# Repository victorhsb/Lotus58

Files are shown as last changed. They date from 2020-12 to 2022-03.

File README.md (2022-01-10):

# Lotus 58

Starting with simple tweaks to the Lily58 Glow before ordering a set of PCB's it quickly spiraled out of control, and I ended up with what wasn't quite a Lily58 anymore, and although very similar in layout, it is no longer compatible with plate and case design. 

Because of this, it was renamed Lotus58, referencing another flower much like the lily in the name Lily58.

# Lotus 58 Glow

Lotus 58 Glow
(photo from reddit by u/bduzik)

- Layout very similar to the original Lily58 family
- Per key RGB and RGB underglow
- Kaihl Hot-swap sockets for MX compatible switches
- Can be used as a standalone Gamepad for either hand
- Optional 0.91" OLED Screens and rotary encoders (one each per side)
- All components through-hole and easily soldered for beginners (SMD option for diodes)
- Designed with a sandwich-style plate/case as part of the design

# Layout variations

- Optional plate layout with OLED screen (Encoder can be placed on upper thumb key position)
- Optional plate layout with rotary encoder (Removes OLED screen for that side)  
- Optional plate layout with no hole for OLED or upper encoder (Encoder can be placed on upper thumb key position)

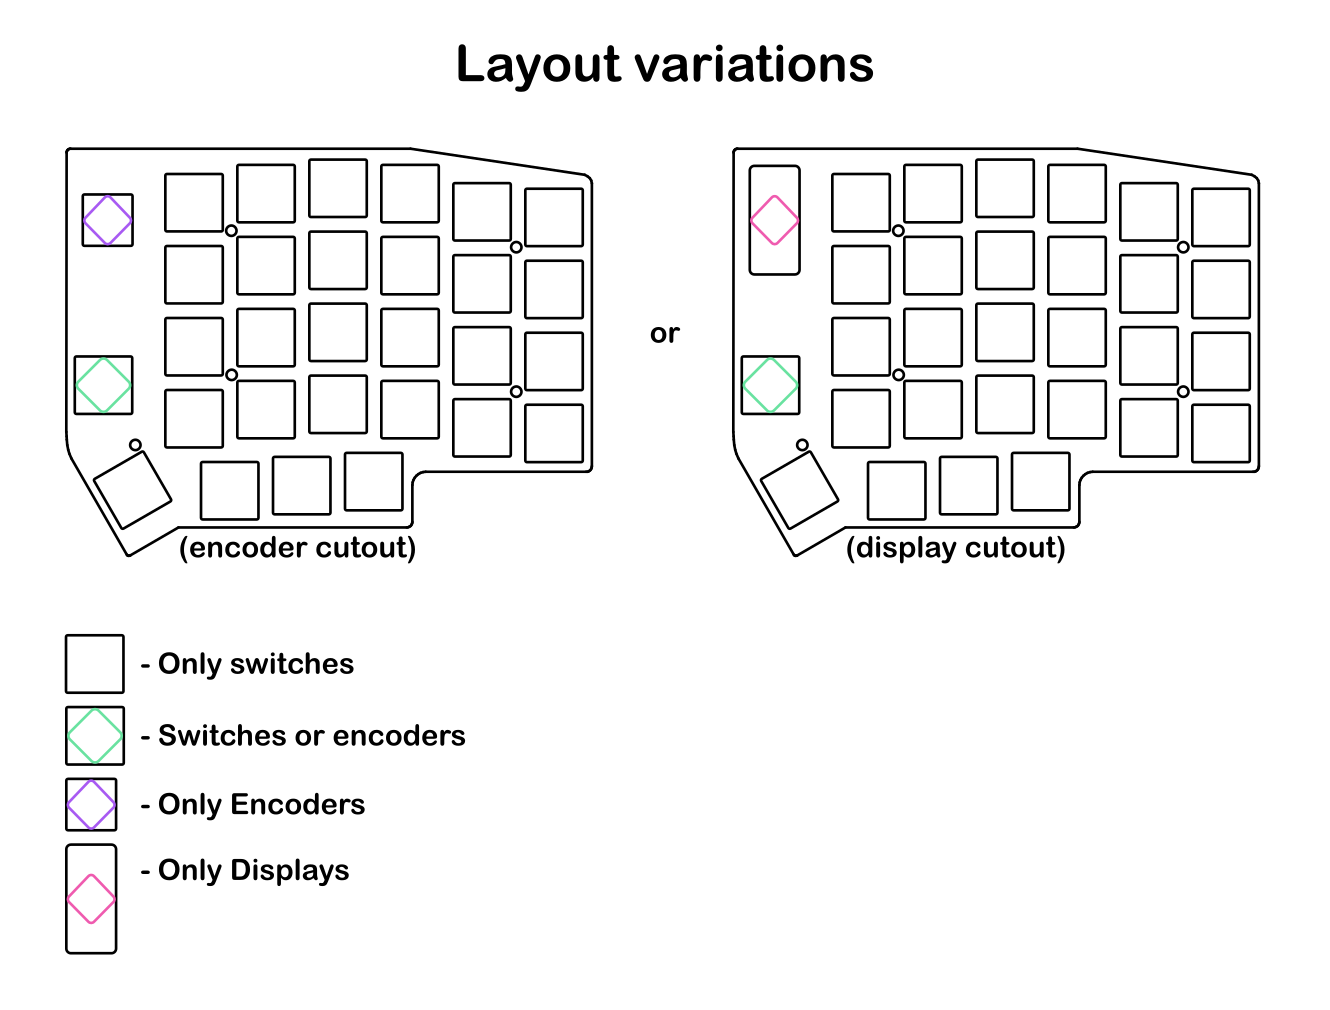
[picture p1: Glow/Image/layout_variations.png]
Layout variations Layout Variations


# Parts needed

| Name of part | Qty. | Optional | Remarks | Aliexpress |
| --- | ---- | --- | --- | --- |
| PCB | 2 | X | 1,6mm thick | X |
| Top plate | 2 | X | Optional layouts for OLED or encoder in top position. | X |
| Bottom plate | 2 | X | X | X |
| Kailh hotswap socket | 56-58 | X | Qty. depends on layout. | [link](https://www.aliexpress.com/item/-/4001051840976.html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) |
| Diodes 1N4841 (TH) or 1N4148W (SMD) | 56-58 | X | Qty. depends on layout. TH recommended for beginners. | [link(TH)](https://www.aliexpress.com/item/HOT-SELL-100-PCS-1N4148-DO-35-IN4148-Silicon-Switching-Diode-FREE-SHIPPMENT/32660088529.html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) or [link(SMD)](https://www.aliexpress.ru/item/-/1005002059571417.html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) |
| Capacitors 100 nF | 0-4 | ✔ | Qty. depends on layout. 2 needed for each encoder installed. | [link](https://www.aliexpress.com/item/-/32971478818.html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) |
| Resistor 4.7 kOhm | 2 | X | Meant to be mounted only on one side | [link](https://www.aliexpress.com/item/-/32847047012.html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) |
| 0.91" OLED Display | 0-2 | ✔ | Qty. depends on layout. | [link](https://www.aliexpress.com/item/-/4001028384269.html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) |
| TRRS jack PJ-320A | 2 | X | X | [link](https://www.aliexpress.com/item/-/4000114275750.html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) |
| M2 * 10 mm standoff | 10 | X | Rounded, max 3.7 mm in diameter | [link](https://www.aliexpress.com/item/-/32863484622.html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) |
| M2 * 4 mm screw | 20 | X | 4-8 mm length fits, low profile hex head recommended | [link](https://www.aliexpress.com/item/-/32966917947.html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) |
| TRRS cable | 1 | X | Needs to be 4 poles, more common 3 poles cable creates a shortcircuit | [link](https://www.aliexpress.com/item/32905903526.html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,searchweb201602_,searchweb201603_) |
| Silicon pads | 10 | X | X | [link](https://www.aliexpress.com/item/-/32912066603.html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) |
| Pro Micro | 2 | X | Can be built with various ProMicro clones as well as Elite C (Or nice!nano for a wireless keyboard) | [link](https://www.aliexpress.com/item/-/32849563958.html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) |
| Rotary Encoder | 0-2 | ✔ | Qty. depends on layout. | [link](https://www.aliexpress.com/item/10000056483250.html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,searchweb201602_,searchweb201603_) |
| Rotary Encoder Knob | 0-2 | ✔ | One needed for each encoder. Clearance for max 24 mm diameter, pick halfshaft or spline according to encoder choice.  | [link](https://www.aliexpress.com/item/10000056483250.html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,searchweb201602_,searchweb201603_) |
| SK6812 mini (3535) | 56-70 | ✔ | Qty. depends on layout. Optional 12 pcs required for underglow. | [link](https://www.aliexpress.com/item/-/4001361956752.html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) |

# Things to note when ordering PCB's

**If you are not aiming at modifying things, don't look for the gerber files in the folders, pretty please! And don't open yet another issue about it! The gerber files are where they belong, zipped up in releases.**

Most PCB manufacturers have a MOQ of 5 PCB's, meaning you end up with 2½ keyboards when finished. To make it possible to build Lotus58 at a reasonable cost, the plate designs use breakaway parts and can easily double as a backplate. For instance, 5 PCB's + 5 OLED plates + 5 Encoder plates give you a couple of options without being wasteful.  

The recommended PCB thickness is 1.6 mm, as the thickness of the SK6812mini RGB LED's are in fact 1.6 mm, making them sit flush 'inside' the PCB and easier to solder. Similarly, for the top plate, a thickness of 1.6 mm is recommended to allow the keyswitches to grip the plate and lock in place securely.

If ordering from [JLPCB](https://www.jlpcb.com) the plate Gerber files include a reference putting the added serial etc on a breakaway part for a clean look with minimal cost, if using another manufacturer it's possible they have additional fee's for removing the extra text, or you should consider plotting the Gerber files yourself with the correct reference for your manufacturer.

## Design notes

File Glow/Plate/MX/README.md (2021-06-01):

#Note
You'll need to use M2 washers with the laser cut plates. This will slightly increase the height, but you could use slightly shorter standoffs to compensate.

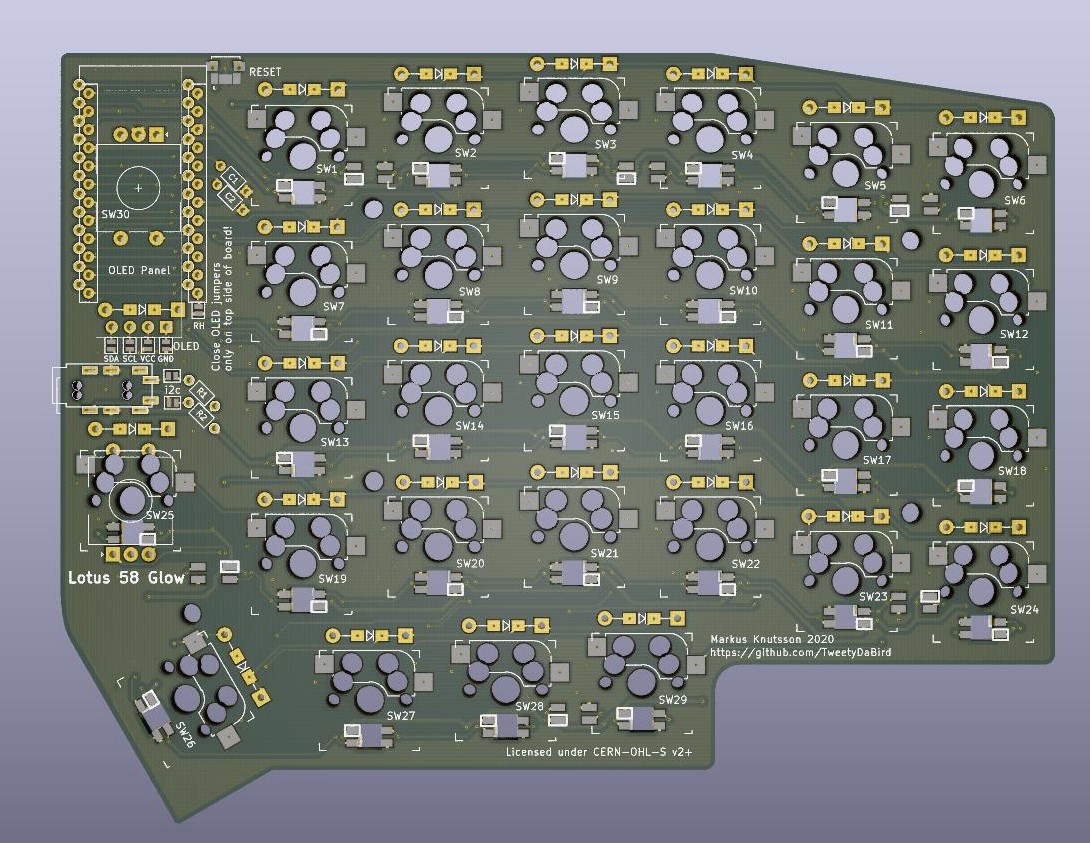
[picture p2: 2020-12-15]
images/Glow_MX.jpg

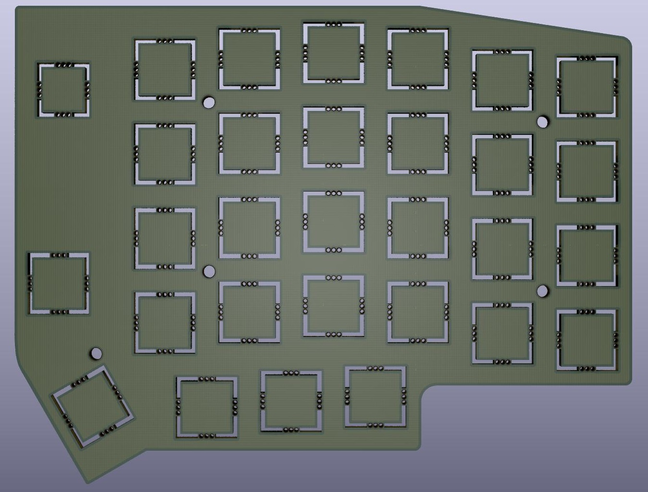
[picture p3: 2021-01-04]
Plate/FR4_Top_Plate.jpg

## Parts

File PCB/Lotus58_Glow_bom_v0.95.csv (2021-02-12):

Component | Description | Part | References | Value | Footprint | Quantity Per PCB | manufacturer | mouser part number | digikey part number
1 | Unpolarized capacitor, small symbol | C_Small | C1 C2 | 100nF | RESISTOR_Reversible | 2
2 | Diode | D | D1 D2 D3 D4 D5 D6 D7 D8 D9 D10 D11 D12 D13 D14 D15 D16 D17 D18 D19 D20 D21 D22 D23 D24 D25 D26 D27 D28 D29 D30 | 1N4148/1N4148W | Diode_DO35_SOD123 | 30
3 | Audio Jack, 4 Poles (TRRS) | AudioJack4 | J1 | PJ-320A | MJ-4PP-9_alim | 1
4 | Jumper, normally open, small symbol | Jumper_NO_Small | JP1 JP2 JP3 JP4 JP5 JP6 JP7 JP8 JP9 JP10 JP11 JP12 JP13 | Jumper_NO_Small | Jumper_Mini | 13
5 | RGB LED with integrated controller | SK6812MINI | L1 L2 L3 L4 L5 L6 L7 L8 L9 L10 L11 L12 L13 L14 L15 L16 L17 L18 L19 L20 L21 L22 L23 L24 L25 L26 L27 L28 L29 | SK6812mini | SK6812MINI_Midmount_Reversible | 29
6 | RGB LED with integrated controller | SK6812MINI | L30 L31 L32 L33 L34 L35 | SK6812mini | SK6812MINI_Reversible | 6
7 | Generic connector, single row, 01x04 | Conn_01x04 | P4 | OLED | SSD1306-0.91-OLED-4pin-128x32 | 1
8 | Resistor | R | R1 R2 | 4k7 | RESISTOR_Reversible | 2
9 | EVP-AKE31A | EVP-AKE31A | RESET1 | EVP-AKE31A | Panasonic-EVP-AKE31A-MFG_reversible | 1 | Panasonic | 667-EVP-AKE31A | P123437CT-ND
10 | Push button switch, generic, two pins | SW_Push | SW1 SW2 SW3 SW4 SW5 SW6 SW7 SW8 SW9 SW10 SW11 SW12 SW13 SW14 SW15 SW16 SW17 SW18 SW19 SW20 SW21 SW22 SW23 SW24 SW25 SW26 SW27 SW28 SW29 | Kailh hotswap MX socket | Kailh_socket_MX_reversible_RGB | 29
11 | Rotary encoder, dual channel, incremental quadrate outputs, with switch | Rotary_Encoder_Switch | SW30 SW31 | Rotary_Encoder_Switch | RotaryEncoder_EC11-no-legs | 2
12 |  | ProMicro | U1 | ProMicro | ProMicro_Reversible | 1
 | Component Groups: | 12
 | Component Count: | 117
 | Fitted Components: | 117
 | Number of PCBs: | 1
 | Total components: | 117
 | Schematic Version: | v0.95
 | Schematic Date: | 2020-12-12
 | PCB Variant: | udefault
 | BoM Date: | 2021-02-12 09:37:48
 | Schematic Source: | Lotus58_Glow.sch
 | KiCad Version: | Eeschema (5.1.9)-1

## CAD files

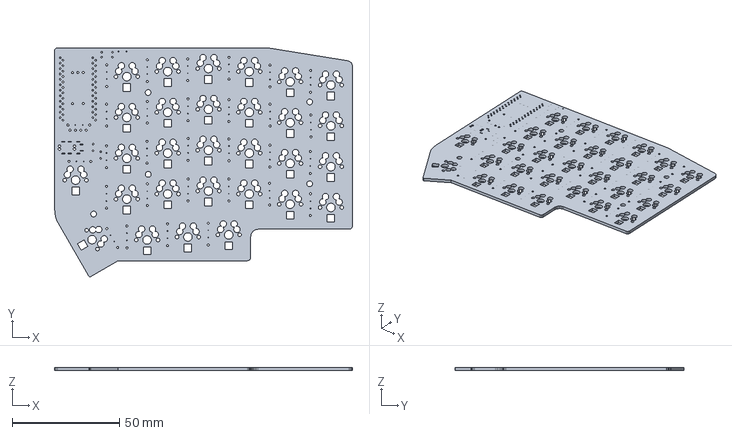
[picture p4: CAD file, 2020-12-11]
PCB/Lotsu58_Glow.step
139.1 x 106.7 x 1.60 mm

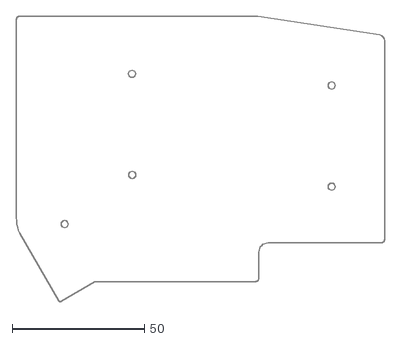
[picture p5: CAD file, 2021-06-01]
Plate/DXF/Laser_Cut_Bottom_Plate-Cuts.dxf
139.1 x 107.7

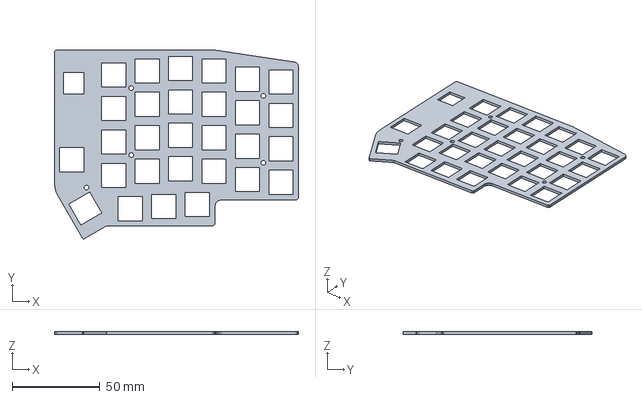
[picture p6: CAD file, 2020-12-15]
Plate/FR4_Top_Plate.step
139.1 x 107.7 x 1.60 mm

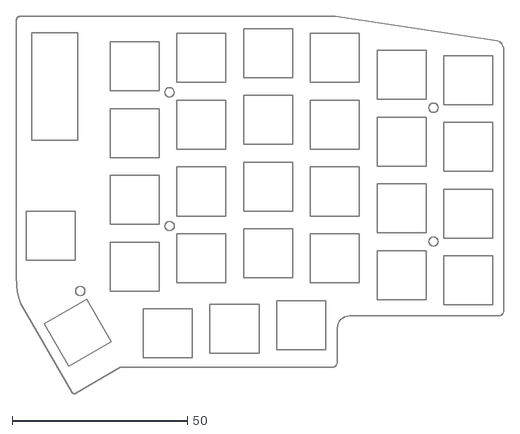
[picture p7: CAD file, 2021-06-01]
Plate/DXF/Laser_Cut_Top_Plate_OLED.dxf
139.1 x 107.7

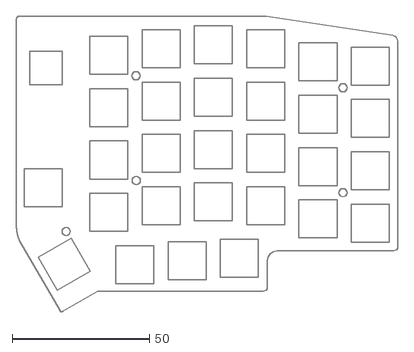
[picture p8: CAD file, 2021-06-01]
Plate/DXF/Laser_Cut_Top_Plate_ENC.dxf
139.0 x 107.7

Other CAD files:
Plate/FR4_Bottom_Plate.step

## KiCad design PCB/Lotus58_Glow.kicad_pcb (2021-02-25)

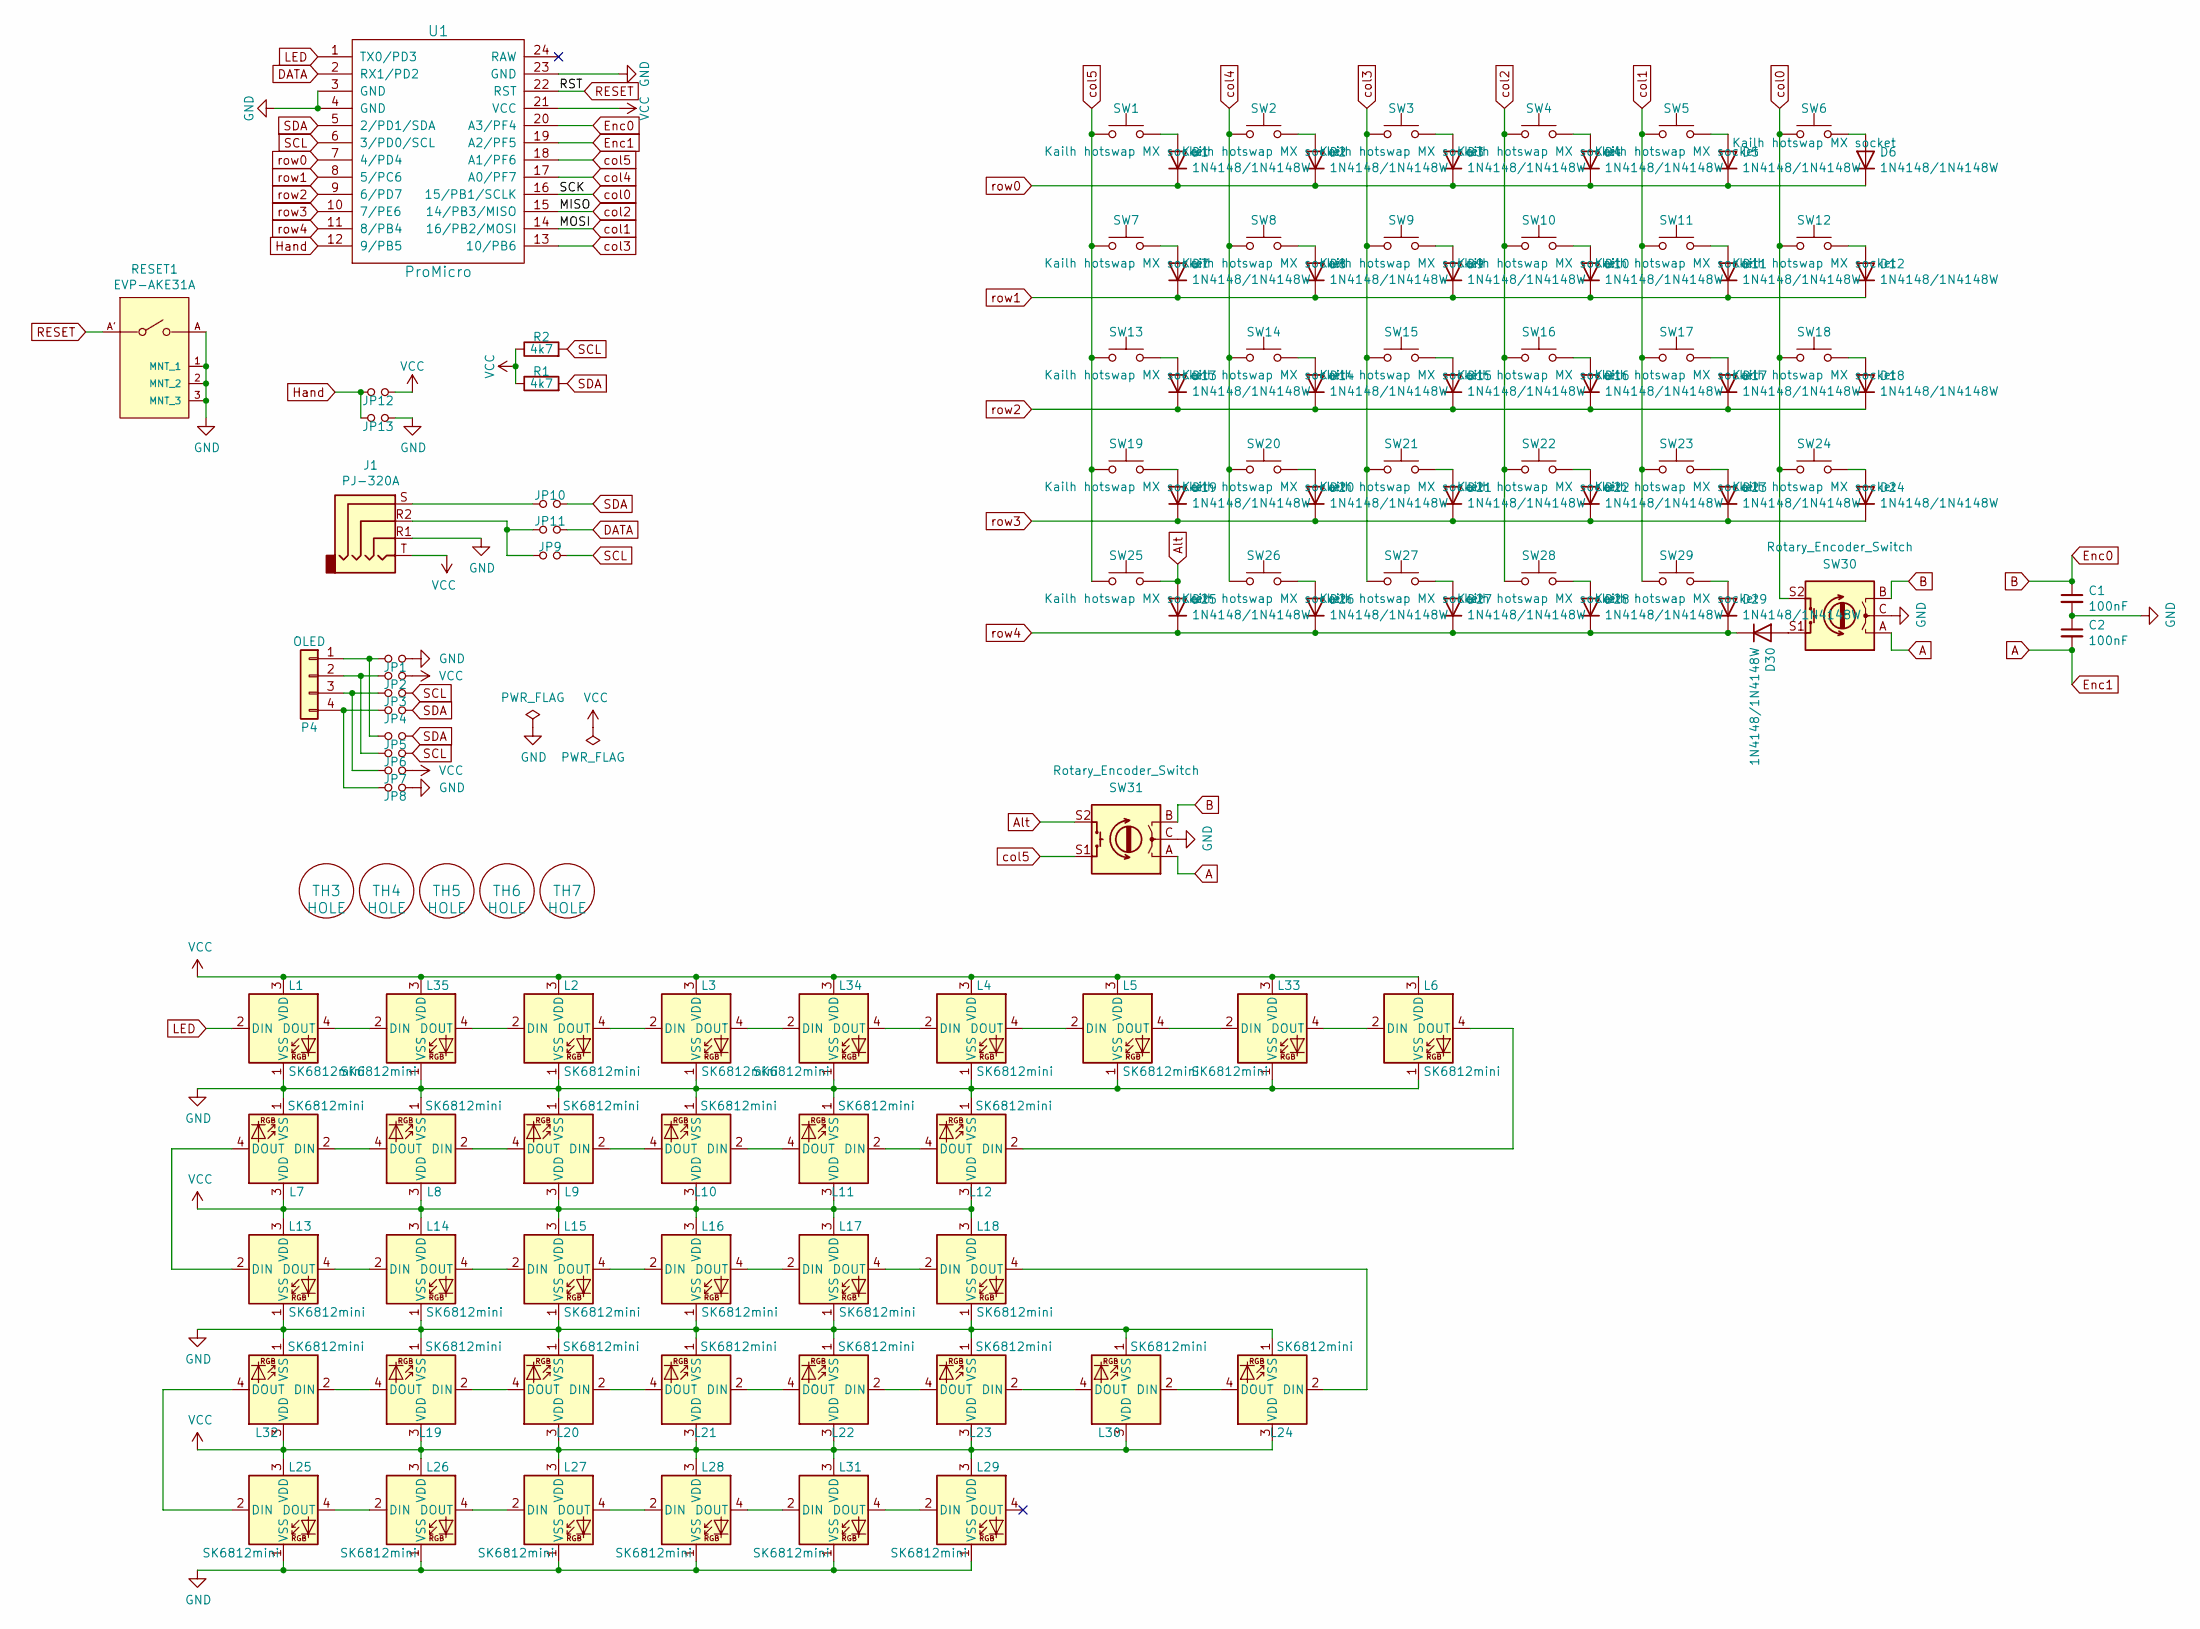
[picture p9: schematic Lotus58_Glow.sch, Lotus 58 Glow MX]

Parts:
C1, C2: 100nF; RESISTOR_Reversible
D1, D2, D3, D4, D5, D6, D7, D8, D9, D10, D11, D12, D13, D14, D15, D16, D17, D18, D19, D20, D21, D22, D23, D24, D25, D26, D27, D28, D29, D30: 1N4148/1N4148W; Diode_DO35_SOD123
J1: PJ-320A; MJ-4PP-9_alim
JP1, JP2, JP3, JP4, JP5, JP6, JP7, JP8, JP9, JP10, JP11, JP12, JP13: Jumper_NO_Small; Jumper_Mini
L1, L2, L3, L4, L5, L6, L7, L8, L9, L10, L11, L12, L13, L14, L15, L16, L17, L18, L19, L20, L21, L22, L23, L24, L25, L26, L27, L28, L29: SK6812mini; SK6812MINI_Midmount_Reversible
L30, L31, L32, L33, L34, L35: SK6812mini; SK6812MINI_Reversible
P4: OLED; SSD1306-0.91-OLED-4pin-128x32
R1, R2: 4k7; RESISTOR_Reversible
RESET1: EVP-AKE31A; Panasonic-EVP-AKE31A-MFG_reversible; voltage rating DC 15V; mouser part number 667-EVP-AKE31A; digikey description 3.8MM X 1.9MM / 1.6N / 0.12MM ST
SW1, SW2, SW3, SW4, SW5, SW6, SW7, SW8, SW9, SW10, SW11, SW12, SW13, SW14, SW15, SW16, SW17, SW18, SW19, SW20, SW21, SW22, SW23, SW24, SW25, SW26, SW27, SW28, SW29: Kailh hotswap MX socket; Kailh_socket_MX_reversible_RGB
SW30, SW31: Rotary_Encoder_Switch; RotaryEncoder_EC11-no-legs
TH3, TH4, TH5, TH6, TH7: HOLE; MountingHole_3.7mm
U1: ProMicro; ProMicro_Reversible

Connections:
A: C2.2, SW30.A, SW31.A, U1.19 (A2/PF5)
Alt: D25.2 (A), SW25.2, SW31.S2
B: C1.1, SW30.B, SW31.B, U1.20 (A3/PF4)
DATA: JP11.2, U1.2 (RX1/PD2)
GND: C1.2, C2.1, J1.R1, JP1.2, JP8.2, JP13.2, L1.1 (VSS), L2.1 (VSS), L3.1 (VSS), L4.1 (VSS), L5.1 (VSS), L6.1 (VSS), L7.1 (VSS), L8.1 (VSS), L9.1 (VSS), L10.1 (VSS), L11.1 (VSS), L12.1 (VSS), L13.1 (VSS), L14.1 (VSS), L15.1 (VSS), L16.1 (VSS), L17.1 (VSS), L18.1 (VSS), L19.1 (VSS), L20.1 (VSS), L21.1 (VSS), L22.1 (VSS), L23.1 (VSS), L24.1 (VSS), L25.1 (VSS), L26.1 (VSS), L27.1 (VSS), L28.1 (VSS), L29.1 (VSS), L30.1 (VSS), L31.1 (VSS), L32.1 (VSS), L33.1 (VSS), L34.1 (VSS), L35.1 (VSS), RESET1.1 (MNT_1), RESET1.2 (MNT_2), RESET1.3 (MNT_3), RESET1.A, SW30.C, SW31.C, U1.3 (GND), U1.4 (GND), U1.23 (GND)
Hand: JP12.1, JP13.1, U1.12 (9/PB5)
LED: L1.2 (DIN), U1.1 (TX0/PD3)
unnamed: D1.2 (A), SW1.2
unnamed: D2.2 (A), SW2.2
unnamed: D3.2 (A), SW3.2
unnamed: D4.2 (A), SW4.2
unnamed: D5.2 (A), SW5.2
unnamed: D6.2 (A), SW6.2
unnamed: D7.2 (A), SW7.2
unnamed: D8.2 (A), SW8.2
unnamed: D9.2 (A), SW9.2
unnamed: D10.2 (A), SW10.2
unnamed: D11.2 (A), SW11.2
unnamed: D12.2 (A), SW12.2
unnamed: D13.2 (A), SW13.2
unnamed: D14.2 (A), SW14.2
unnamed: D15.2 (A), SW15.2
unnamed: D16.2 (A), SW16.2
unnamed: D17.2 (A), SW17.2
unnamed: D18.2 (A), SW18.2
unnamed: D19.2 (A), SW19.2
unnamed: D20.2 (A), SW20.2
unnamed: D21.2 (A), SW21.2
unnamed: D22.2 (A), SW22.2
unnamed: D23.2 (A), SW23.2
unnamed: D24.2 (A), SW24.2
unnamed: D26.2 (A), SW26.2
unnamed: D27.2 (A), SW27.2
unnamed: D28.2 (A), SW28.2
unnamed: D29.2 (A), SW29.2
unnamed: D30.2 (A), SW30.S1
unnamed: J1.R2, JP9.2, JP11.1
unnamed: J1.S, JP10.1
unnamed: JP1.1, JP5.1, P4.1
unnamed: JP2.1, JP6.1, P4.2
unnamed: JP3.1, JP7.1, P4.3
unnamed: JP4.1, JP8.1, P4.4
unnamed: L1.4 (DOUT), L35.2 (DIN)
unnamed: L2.2 (DIN), L35.4 (DOUT)
unnamed: L2.4 (DOUT), L3.2 (DIN)
unnamed: L3.4 (DOUT), L34.2 (DIN)
unnamed: L4.4 (DOUT), L5.2 (DIN)
unnamed: L7.2 (DIN), L8.4 (DOUT)
unnamed: L8.2 (DIN), L9.4 (DOUT)
unnamed: L10.2 (DIN), L11.4 (DOUT)
unnamed: L9.2 (DIN), L10.4 (DOUT)
unnamed: L11.2 (DIN), L12.4 (DOUT)
unnamed: L6.4 (DOUT), L12.2 (DIN)
unnamed: L7.4 (DOUT), L13.2 (DIN)
unnamed: L13.4 (DOUT), L14.2 (DIN)
unnamed: L14.4 (DOUT), L15.2 (DIN)
unnamed: L15.4 (DOUT), L16.2 (DIN)
unnamed: L16.4 (DOUT), L17.2 (DIN)
unnamed: L17.4 (DOUT), L18.2 (DIN)
unnamed: L18.4 (DOUT), L24.2 (DIN)
unnamed: L19.2 (DIN), L20.4 (DOUT)
unnamed: L19.4 (DOUT), L32.2 (DIN)
unnamed: L20.2 (DIN), L21.4 (DOUT)
unnamed: L21.2 (DIN), L22.4 (DOUT)
unnamed: L22.2 (DIN), L23.4 (DOUT)
unnamed: L23.2 (DIN), L30.4 (DOUT)
unnamed: L24.4 (DOUT), L30.2 (DIN)
unnamed: L25.2 (DIN), L32.4 (DOUT)
unnamed: L25.4 (DOUT), L26.2 (DIN)
unnamed: L26.4 (DOUT), L27.2 (DIN)
unnamed: L27.4 (DOUT), L28.2 (DIN)
unnamed: L28.4 (DOUT), L31.2 (DIN)
unnamed: L29.2 (DIN), L31.4 (DOUT)
unnamed: L5.4 (DOUT), L33.2 (DIN)
unnamed: L6.2 (DIN), L33.4 (DOUT)
unnamed: L4.2 (DIN), L34.4 (DOUT)
RESET: RESET1.A', U1.22 (RST)
SCL: JP3.2, JP6.2, JP9.1, R2.2, U1.6 (3/PD0/SCL)
SDA: JP4.2, JP5.2, JP10.2, R1.2, U1.5 (2/PD1/SDA)
VCC: J1.T, JP2.2, JP7.2, JP12.2, L1.3 (VDD), L2.3 (VDD), L3.3 (VDD), L4.3 (VDD), L5.3 (VDD), L6.3 (VDD), L7.3 (VDD), L8.3 (VDD), L9.3 (VDD), L10.3 (VDD), L11.3 (VDD), L12.3 (VDD), L13.3 (VDD), L14.3 (VDD), L15.3 (VDD), L16.3 (VDD), L17.3 (VDD), L18.3 (VDD), L19.3 (VDD), L20.3 (VDD), L21.3 (VDD), L22.3 (VDD), L23.3 (VDD), L24.3 (VDD), L25.3 (VDD), L26.3 (VDD), L27.3 (VDD), L28.3 (VDD), L29.3 (VDD), L30.3 (VDD), L31.3 (VDD), L32.3 (VDD), L33.3 (VDD), L34.3 (VDD), L35.3 (VDD), R1.1, R2.1, U1.21 (VCC)
col0: SW6.1, SW12.1, SW18.1, SW24.1, SW30.S2, U1.16 (15/PB1/SCLK)
col1: SW5.1, SW11.1, SW17.1, SW23.1, SW29.1, U1.14 (16/PB2/MOSI)
col2: SW4.1, SW10.1, SW16.1, SW22.1, SW28.1, U1.15 (14/PB3/MISO)
col3: SW3.1, SW9.1, SW15.1, SW21.1, SW27.1, U1.13 (10/PB6)
col4: SW2.1, SW8.1, SW14.1, SW20.1, SW26.1, U1.17 (A0/PF7)
col5: SW1.1, SW7.1, SW13.1, SW19.1, SW25.1, SW31.S1, U1.18 (A1/PF6)
row0: D1.1 (K), D2.1 (K), D3.1 (K), D4.1 (K), D5.1 (K), D6.1 (K), U1.7 (4/PD4)
row1: D7.1 (K), D8.1 (K), D9.1 (K), D10.1 (K), D11.1 (K), D12.1 (K), U1.8 (5/PC6)
row2: D13.1 (K), D14.1 (K), D15.1 (K), D16.1 (K), D17.1 (K), D18.1 (K), U1.9 (6/PD7)
row3: D19.1 (K), D20.1 (K), D21.1 (K), D22.1 (K), D23.1 (K), D24.1 (K), U1.10 (7/PE6)
row4: D25.1 (K), D26.1 (K), D27.1 (K), D28.1 (K), D29.1 (K), D30.1 (K), U1.11 (8/PB4)

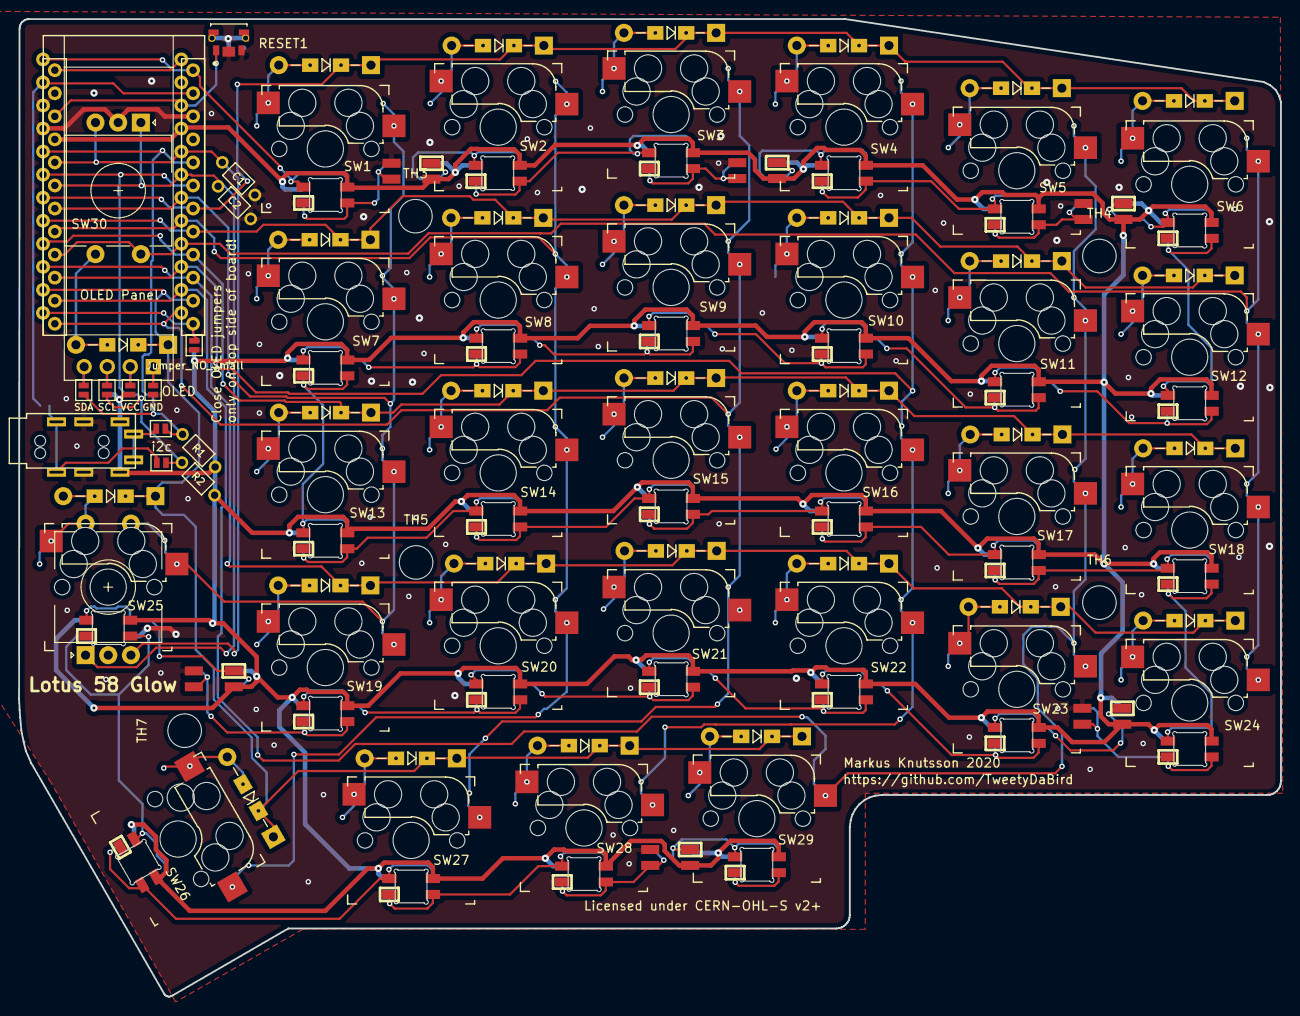
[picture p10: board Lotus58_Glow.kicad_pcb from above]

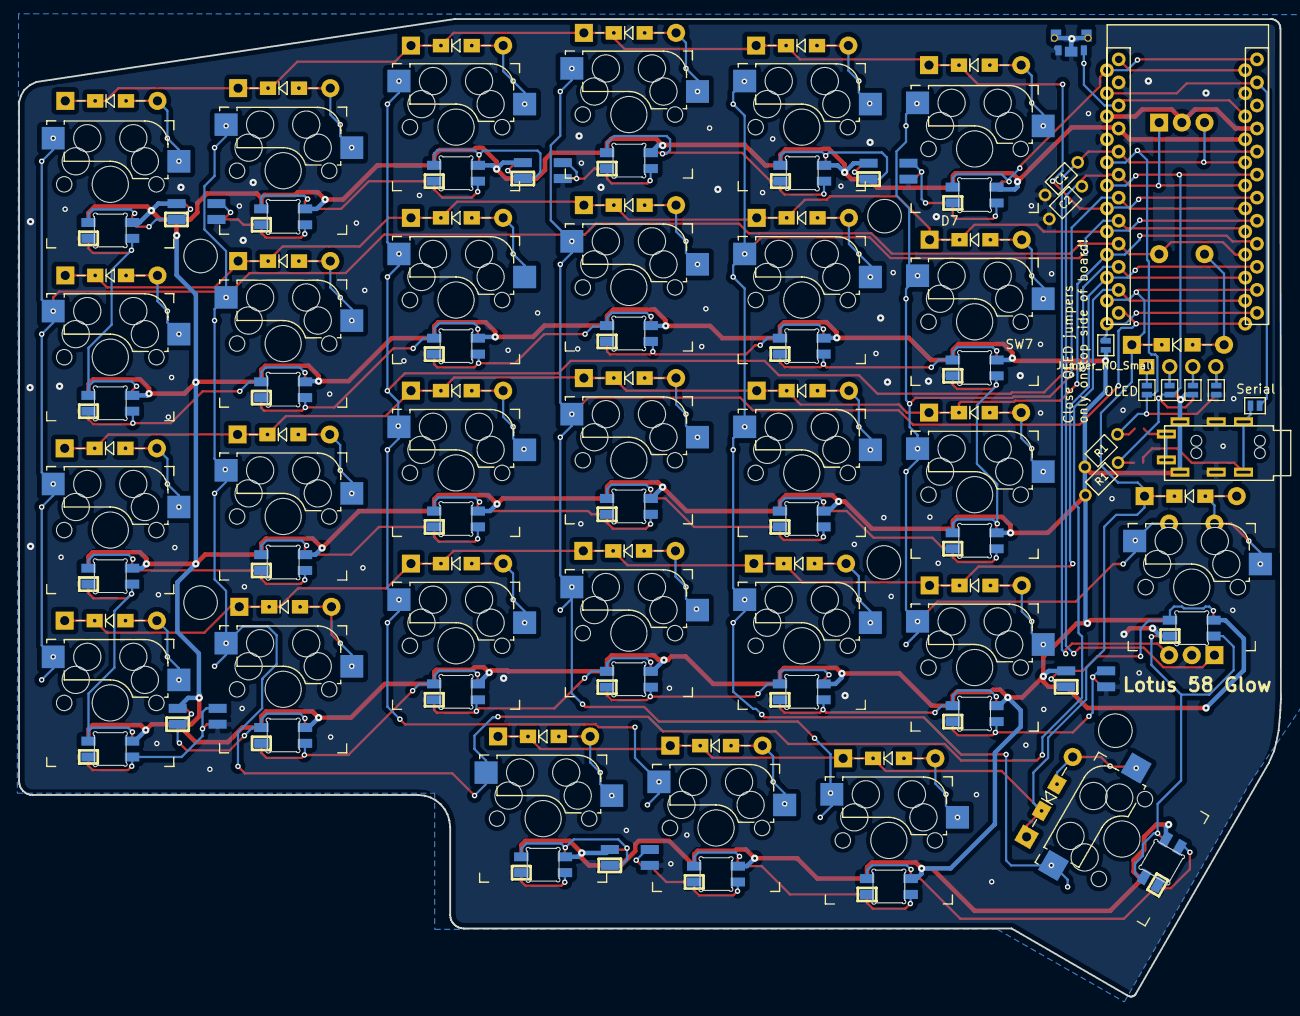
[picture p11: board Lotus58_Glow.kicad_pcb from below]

Board: 2 copper layers, 139.1 x 107.7 mm, 122 parts (39 on the bottom side), 91 nets.

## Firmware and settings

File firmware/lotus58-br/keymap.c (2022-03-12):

 /* Copyright 2017 F_YUUCHI
  * Copyright 2020 Drashna Jaelre <@drashna>
  * Copyright 2020 Ben Roesner (keycapsss.com)
  *
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
  * You should have received a copy of the GNU General Public License
  * along with this program.  If not, see <http://www.gnu.org/licenses/>.
  */

#include QMK_KEYBOARD_H


extern uint8_t is_master;

enum layers {
    _QWERTY,
    _LOWER,
    _RAISE,
    _ADJUST,
};

#define RAISE MO(_RAISE)
#define LOWER MO(_LOWER)

/* Copyright 2017 Potiguar Faga
 *
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
 * You should have received a copy of the GNU General Public License
 * along with this program.  If not, see <http://www.gnu.org/licenses/>.
 */

#ifndef KEYMAP_BR_ABNT2_H
#define KEYMAP_BR_ABNT2_H

#include "keymap.h"

/* Scan codes for the Brazilian ABNT2 keyboard layout */

#define BR_CCDL KC_SCLN  //  Ç   same scancode as ;: on US layout
#define BR_SCLN KC_SLSH  //  ;:  same scancode as /? on US layout
#define BR_QUOT KC_GRV   //  '"  same scancode as `~ on US layout
#define BR_TILD KC_QUOT  //  ~^  dead keys, same scancode as '" on US layout
#define BR_ACUT KC_LBRC  //  ´`  dead keys, same scancode as [{ on US layout
#define BR_LBRC KC_RBRC  //  [{  same scancode as ]} on US layout
#define BR_RBRC KC_BSLS  //  ]}  same scancode as \| on US layout
#define BR_BSLS KC_NUBS  //  \|  uses the non-US hash scancode (#~, sometimes §±)
#define BR_SLSH KC_INT1  //  /?  uses the INTL1 scancode

#define BR_COLN LSFT(BR_SCLN)  // shifted :
#define BR_DQT LSFT(BR_QUOT)   // shifted "
#define BR_CIRC LSFT(BR_TILD)  // shifted ^ (dead key)
#define BR_GRAV LSFT(BR_ACUT)  // shifted ` (dead key)
#define BR_LCBR LSFT(BR_LBRC)  // shifted {
#define BR_RCBR LSFT(BR_RBRC)  // shifted }
#define BR_PIPE LSFT(BR_BSLS)  // shifted |
#define BR_QUES LSFT(BR_SLSH)  // shifted ?
#define BR_TRMA LSFT(KC_6)     // shifted ¨ (dead key - trema accent)

// On the ABNT2 the keypad comma and the keypad dot scancodes are switched
// (presumably because in Brazil comma is used as the decimal separator)
#define BR_KPDT KC_KP_COMMA  //  keypad .
#define BR_KPCM KC_KP_DOT    //  keypad ,

#define BR_1UP LALT(KC_1)      // 1 superscript                    ¹   alt+1
#define BR_2UP LALT(KC_2)      // 2 superscript                    ²   alt+2
#define BR_3UP LALT(KC_3)      // 3 superscript                    ³   alt+3
#define BR_PND LALT(KC_4)      // Pound sign                       £   alt+4
#define BR_CENT LALT(KC_5)     // Cent sign                        ¢   alt+5
#define BR_NOT LALT(KC_6)      // Not sign                         ¬   alt+6
#define BR_SECT LALT(KC_EQL)   // Section sign                     §   alt+=
#define BR_FORD LALT(BR_LBRC)  // Feminine Ordinal Sign            ª   alt+[
#define BR_MORD LALT(BR_RBRC)  // Masculine Ordinal Sign           º   alt+]
#define BR_DGRE LALT(BR_SLSH)  // Degree sign                      °   alt+/

#define BR_EURO LALT(KC_E)     // Euro sign                        €   alt+e
#define BR_NDTD LALT(BR_TILD)  // Non-dead key tilde               ~   alt+~
#define BR_NDAC LALT(BR_ACUT)  // Non-dead key acute accent        ´   alt+´
#define BR_NDGV LALT(BR_QUOT)  // Non-dead key grave accent        `   alt+'
#define BR_NDCR LALT(BR_CIRC)  // Non-dead key circumflex accent   ^   alt+^ (alt+shift+~)
#define BR_NDTR LALT(BR_TRMA)  // Non-dead key trema accent        ¨   alt+¨ (alt+shift+6)

// For 101-key keyboard layouts, the ABNT2 layout allows
// the slash and question mark to be typed using alt+q and alt+w.
// The shortcuts are provided here for completeness' sake,
// but it's recommended to use BR_SLSH and BR_QUES instead
#define BR_ASLS LALT(KC_Q)
#define BR_AQST LALT(KC_W)

#endif

const uint16_t PROGMEM keymaps[][MATRIX_ROWS][MATRIX_COLS] = {

/* QWERTY
 * ,-----------------------------------------.                    ,-----------------------------------------.
 * | ESC  |   1  |   2  |   3  |   4  |   5  |                    |   6  |   7  |   8  |   9  |   0  |  '   |
 * |------+------+------+------+------+------|                    |------+------+------+------+------+------|
 * | Tab  |   Q  |   W  |   E  |   R  |   T  |                    |   Y  |   U  |   I  |   O  |   P  |  ´   |
 * |------+------+------+------+------+------|                    |------+------+------+------+------+------|
 * |LShift|   A  |   S  |   D  |   F  |   G  |-------.    ,-------|   H  |   J  |   K  |   L  |   ç  |  ~   |
 * |------+------+------+------+------+------|   [   |    |  ply  |------+------+------+------+------+------|
 * |LCTRL |   Z  |   X  |   C  |   V  |   B  |-------|    |-------|   N  |   M  |   ,  |   .  |   ;  |  /   |
 * `-----------------------------------------/       /     \      \-----------------------------------------'
 *                   | LGUI | LALT |LOWER | /Space  /       \Enter \  |RAISE |BackSP| App  |
 *                   |      |      |      |/       /         \      \ |      |      |      |
 *                   `----------------------------'           '------''--------------------'
 */
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

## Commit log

2019-07-19 Create version with in-switch SK6812mini LEDs
    [Lily58.kicad_pcb, Lily58.sch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]
2019-07-19 Tighten up some traces
    [Lily58.kicad_pcb]
2019-07-19 Remove old gerber files
    [Lily58-F.Cu.GTL]
2019-07-20 Update SK6812mini footprint
    [Lily58.kicad_pcb]
2019-07-20 Add underglow
    [Lily58.kicad_pcb, Lily58.sch]
2019-07-20 Clean up routing new thumb key
    [Lily58.kicad_pcb]
2019-07-28 Add ground planes
    [Lily58.kicad_pcb]
2019-09-03 Add some branding
    [Lily58.kicad_pcb]
2019-09-03 Move files to root directory
    [Lily58.kicad_pcb, Lily58.sch, Lily58_Pro.kicad_pcb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]
2020-12-10 New design
    [Lily58_HS_RGB.kicad_pcb, Lily58_HS_RGB.sch]
2020-12-11 Start of Choc
    [Lily58.kicad_pcb, Lily58.sch, Lily58_Choc_HS_RGB.kicad_pcb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]
2020-12-11 moving files
    [Lily58_Choc_HS_RGB.kicad_pcb, Lily58_Choc_HS_RGB.sch]
2020-12-11 Added Plate files
    [FR4_Bottom_Plate.kicad_pcb, FR4_Bottom_Plate.step, FR4_Top_Plate.kicad_pcb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]
2020-12-11 added gerbers MX version
    [FR4_Bottom_Plate.kicad_pcb, FR4_Top_Plate.kicad_pcb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]
2020-12-12 Rename and Cleanup
    [FR4_Bottom_Plate.kicad_pcb, FR4_Bottom_Plate.step, FR4_Top_Plate.kicad_pcb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]
2020-12-12 Added optional encoder layout
    [Lotus58_Glow.kicad_pcb, Lotus58_Glow.sch, Louts58_Glow.sch]
2020-12-12 Updated silkscreen
    New name!
    [Lotus58_Glow.kicad_pcb, Lotus58_Glow.sch]
2020-12-15 Revised footprint
    [Lotus58_Glow.kicad_pcb, Lotus58_Glow.sch, Lotus58_Glow_Choc.kicad_pcb]
2020-12-15 Updated Plates
    [FR4_Bottom_Plate.kicad_pcb, FR4_Bottom_Plate.step, FR4_Top_Plate.kicad_pcb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]
2021-01-04 Adjusted plate
    [FR4_Top_Plate.kicad_pcb, Lotus58_Glow.sch]
2021-01-27 Rearranging folders
    [FR4_Bottom_Plate.kicad_pcb, FR4_Bottom_Plate.step, FR4_Top_Plate.kicad_pcb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]
2021-01-27 Created Wireless
    [Lotus58_Wireless.kicad_pcb, Lotus58_Wireless.sch]
2021-02-08 RGB midmount footprints
    Fixed mirror image pinout
    [Lotus58_Glow.kicad_pcb, Lotus58_Glow.sch, Lotus58_Wireless.kicad_pcb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]
2021-02-12 Component values/BOM added
    [Lotus58_Glow-B_Cu.gbr, Lotus58_Glow-B_Mask.gbr, Lotus58_Glow-B_SilkS.gbr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]
2021-02-12 BOM file updated
    [Lotus58_Glow_bom_v0.95.csv]
2021-02-15 Added OLED to plate design
    [FR4_Top_Plate_ENC.kicad_pcb, FR4_Top_Plate_OLED.kicad_pcb]
2021-02-15 Update README.md
    Not that there cannot be 4 encoders installed.
2021-02-15 Gerbers an zip moved to releases
2021-02-16 Blank front plate option added
    [FR4_Bottom_Plate.kicad_pcb, FR4_Top_Plate.kicad_pcb, FR4_Top_Plate_BLANK.kicad_pcb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]
2021-02-25 Corrected mounting holes
2021-03-04 Update README.md
    Added explanation on RGB LED's.
2021-03-04 Updated plates to remove break-away parts
    [FR4_Top_Plate_BLANK.kicad_pcb, FR4_Top_Plate_ENC.kicad_pcb, FR4_Top_Plate_OLED.kicad_pcb]
2021-03-15 Minor changes to silkscreen
    - Added missing lables for jumpers
    - Removed labels for holes(?)
    - Corrected marker for RGB LED's
    [Lotus58_Glow.kicad_pcb, Lotus58_Glow.sch]
2021-05-17 Update README.md
    Added information about reset switch.
2021-05-21 add dxf files for laser cut plates
    [Laser_Cut_Bottom_Plate-Cuts.dxf, Laser_Cut_Top_Plate_OLED.dxf]
2021-05-29 Add dxf for top plate with encoder cutout
    [Laser_Cut_Top_Plate_ENC.dxf]
2021-06-01 Added Bottom Plate
    With M3 holes for tent/tilt
    [FR4_Bottom_Plate_TENT.kicad_pcb]
2021-06-01 Renamed/moved files
    Laser cut plates in a separate folder
    [FR4_Bottom_Plate.kicad_pcb, FR4_Bottom_Plate.step, FR4_Bottom_Plate_TENT.kicad_pcb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]
2021-08-12 Fixed Spelling mistake "Lotsu" to "Lotus"
    [Lotus58_Glow.step]
2021-08-13 Fixed Wrong No TENT bottom plate
    [FR4_Bottom_Plate.kicad_pcb, Lotus58_Glow.kicad_pcb]
2021-10-07 Updated PCB
    [Lotus58_Glow.kicad_pcb, Lotus58_Glow.sch, Lotus58_Glow_Choc.kicad_pcb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]
2021-10-14 Updated PCB
    Split RGB for under-glow and per-key.
    Added capacitors on RGB.
    Edited encoder footprint for ESD grounding.
    OLED display repositioned.
    Simplified i2c/serial.
    Simplified reset.
    [Lotus58_Glow.kicad_pcb, Lotus58_Glow.sch]
2021-10-19 General Housekeeping
    [FR4_Bottom_Plate.kicad_pcb, FR4_Bottom_Plate.step, FR4_Bottom_Plate_TENT.kicad_pcb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]
2021-10-19 More Housekeeping
    [FR4_Bottom_Plate.kicad_pcb, FR4_Bottom_Plate.step, FR4_Top_Plate.step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]
2021-12-17 replaced DXF files
    [Laser_Cut_Bottom_Plate-Cuts.dxf, Laser_Cut_Top_Plate_ENC.dxf, Laser_Cut_Top_Plate_OLED.dxf]
2022-02-11 restore plate DXF files
    The original files were corrupted in
    https://github.com/TweetyDaBird/Lotus58/commit/1c34fa41cd076e58e1640e762ec52977901df85a
    and this commit brings the original files forward without modification.
    Closes https://github.com/TweetyDaBird/Lotus58/issues/31
    [Laser_Cut_Bottom_Plate-Cuts.dxf, Laser_Cut_Top_Plate_ENC.dxf, Laser_Cut_Top_Plate_OLED.dxf]

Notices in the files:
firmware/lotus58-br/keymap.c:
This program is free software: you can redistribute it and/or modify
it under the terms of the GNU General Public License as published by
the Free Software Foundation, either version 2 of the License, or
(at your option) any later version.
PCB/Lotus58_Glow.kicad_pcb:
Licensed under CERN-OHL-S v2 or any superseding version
